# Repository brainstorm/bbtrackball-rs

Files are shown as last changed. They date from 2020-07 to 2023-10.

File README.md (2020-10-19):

# :mouse: Blackberry rusty mouse

The purpose of this project is to build a [blackberry-trackball mouse][bb_trackball] and glue it to the middle of [an (allegedly) ergonomic keyboard][microsoft_natural_keyboard_4000]... **in Rust Embedded**, for the [STM32F042][stm32f042] :)

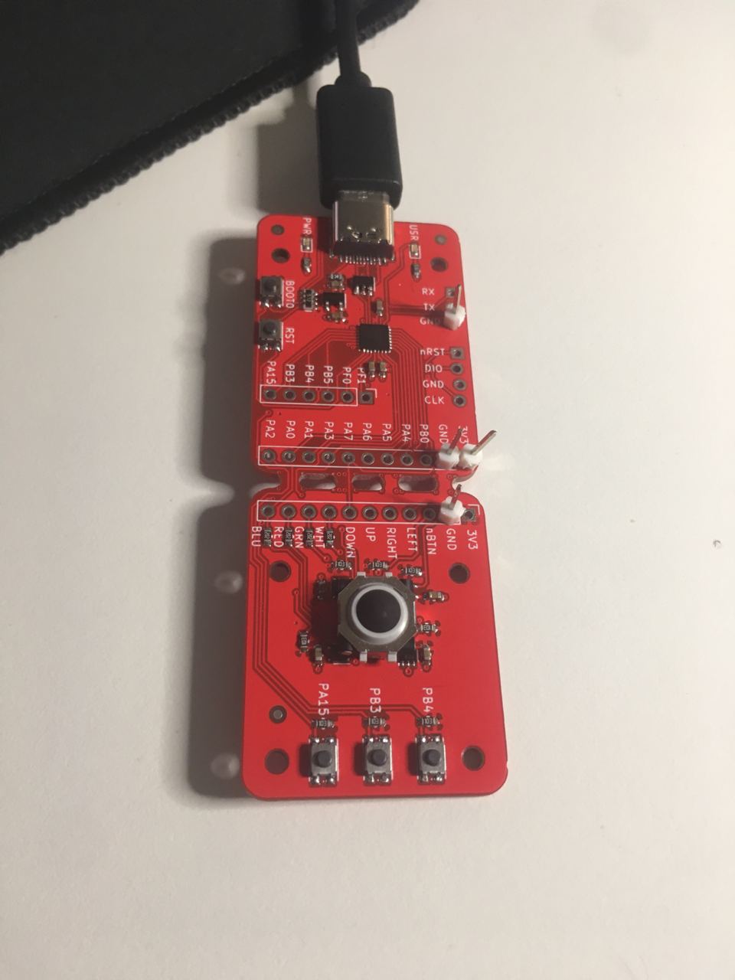
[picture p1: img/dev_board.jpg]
dev_board


This came about [from twitter idea to board, then to Rust Embedded](https://twitter.com/braincode/status/1275406584714104833). The code is based on [RTIC][rtic] rust-embedded framework (formerly known as RTFM). It exclusively uses interrupts *and* [also works on OSX, not only Linux][osx_not_working] (wink wink, nudge nudge, [James][jamesmunns] ;P).

## :rocket: Future improvements shall you take this code with you

* DPI tweaking to have a better trackball accuracy or speed/stepping.
* [Button debouncer][debouncer].
* Remove one of the buttons of the <acronym title="Printed Circuit Board">PCB</acronym>, since it conflicts with one of the trackball GPIOs... oops, hardware blopper ;)
* Add acceleration [like @LSChyi did][add_accel]?
* Perhaps a clever (optical) system to make this experiment actually practical and useful :P
* On OSX the mouse works fine. **On GNU/Linux systems, the mouse might stop responding after ~30 seconds of use**. [This could be related to the Linux USB autosuspend subsystem.](https://askubuntu.com/questions/185274/how-can-i-disable-usb-autosuspend-for-a-specific-device). Try to fix that from the firmware so that it works everywhere?
* If enough people show interest and [**choose to sponsor me**][gh_sponsor_1], I would love to look at how to:
	1. Understand the flash process of the [Beken 3231][beken3231].
	2. Implement an LLVM backend for the [ARM968E-S][ARM968E-S] and have `rustc` working with it.
	3. Goal: **have a sub-$1 bluetooth IC that potentially does all we need and more** plus learn to [implement an LLVM backend from scratch][llvm_cpu0]. Also provide [**a way to upcycle bluetooth hardware, keeping it away from the dumpster.**][old_beken_hardware]
* ~~[Write a simplified RTIC example to return the favour to that amazing rust-embedded community][rtic_hid_example]~~: [Done][rtic_pr].

## :clap: Special thanks to

[@joshajohnson][joshajohnson]
[@mvirkkunen][lumpio]
[@therealprof][therealprof]
[@jamesmunns][jamesmunns]
[@TeXitoi][texitoi]
[@TheZoq2][thezoq2]

And all the folks from the [RTIC matrix.org community][rtic_matrix] for patiently guiding and helping me in this experiment.

[bb_trackball]: https://os.mbed.com/users/AdamGreen/notebook/blackberrytrackballmouse/
[joshajohnson]: https://github.com/joshajohnson
[lumpio]: https://github.com/mvirkkunen/
[therealprof]: https://github.com/therealprof/
[rtic]: https://rtic.rs/
[jamesmunns]: https://github.com/jamesmunns
[osx_not_working]: https://github.com/jamesmunns/OtterPill-rs/commit/8e68fbd5bb1161d8131a99d98c90c3e949f49ec1
[rtic_hid_example]: https://github.com/rtic-rs/rtic-examples/issues/10#issuecomment-677464683
[add_accel]: https://github.com/LSChyi/blackberry-mini-trackball
[debouncer]: https://crates.io/crates/unflappable
[microsoft_natural_keyboard_4000]: https://www.microsoft.com/accessories/en-us/products/keyboards/natural-ergonomic-keyboard-4000/b2m-00012
[stm32f042]: https://www.st.com/en/microcontrollers-microprocessors/stm32f0-series.html
[rtic_pr]: https://github.com/rtic-rs/rtic-examples/pull/12
[gh_sponsor_1]: https://github.com/login?return_to=%2Fsponsors%2Fbrainstorm%2Fsponsorships%3Ftier_id%3D27561
[mitxela]: https://mitxela.com/forum/topic/beken-bk3231
[ARM968E-S]: https://static.docs.arm.com/ddi0311/d/DDI0311.pdf
[beken3231]: https://pdfhost.io/v/3r1I3HggE_BK3231_Bluetooth_HID_SoCpdf.pdf
[llvm_cpu0]: http://jonathan2251.github.io/lbd/TutorialLLVMBackendCpu0.pdf
[texitoi]: https://github.com/TeXitoi
[thezoq2]: https://gitlab.com/TheZoq2/hotas
[old_beken_hardware]: https://mitxela.com/forum/topic/mocute-051-bluetooth-gamepad-bk3231-change-hid-profile-from-keyboard-gamepad
[rtic_matrix]: https://matrix.to/#/#rtic:matrix.org

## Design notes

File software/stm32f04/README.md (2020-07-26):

# Rust STM32 blackberry trackball firmware

Getting onboard with Rust for embedded devices is like 1,2,3 (more details on the [Rust embedded book](https://rust-embedded.github.io/book/)):

```shell
$ curl --proto '=https' --tlsv1.2 -sSf https://sh.rustup.rs | sh
$ rustup target add thumbv6m-none-eabi
$ cargo install cargo-embed
```

Flashing with a standard STLink v2 is easy with `cargo-embed`:

```shell
$ cargo embed --release
    Finished release [optimized] target(s) in 0.04s
    Flashing /Users/romanvg/dev/cchs/keyboard_trackball/software/stm32f04/target/thumbv6m-none-eabi/release/stm32f042
     Erasing sectors ✔ [00:00:00] [#################################################################]  23.00KB/ 23.00KB @  28.29KB/s (eta 0s )
 Programming pages   ✔ [00:00:02] [#################################################################]  23.00KB/ 23.00KB @   7.24KB/s (eta 0s )
    Finished in 2.942s
```

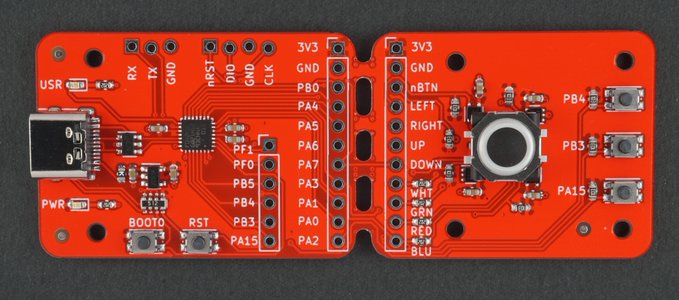
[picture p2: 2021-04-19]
img/josh_studio_photo.jpg

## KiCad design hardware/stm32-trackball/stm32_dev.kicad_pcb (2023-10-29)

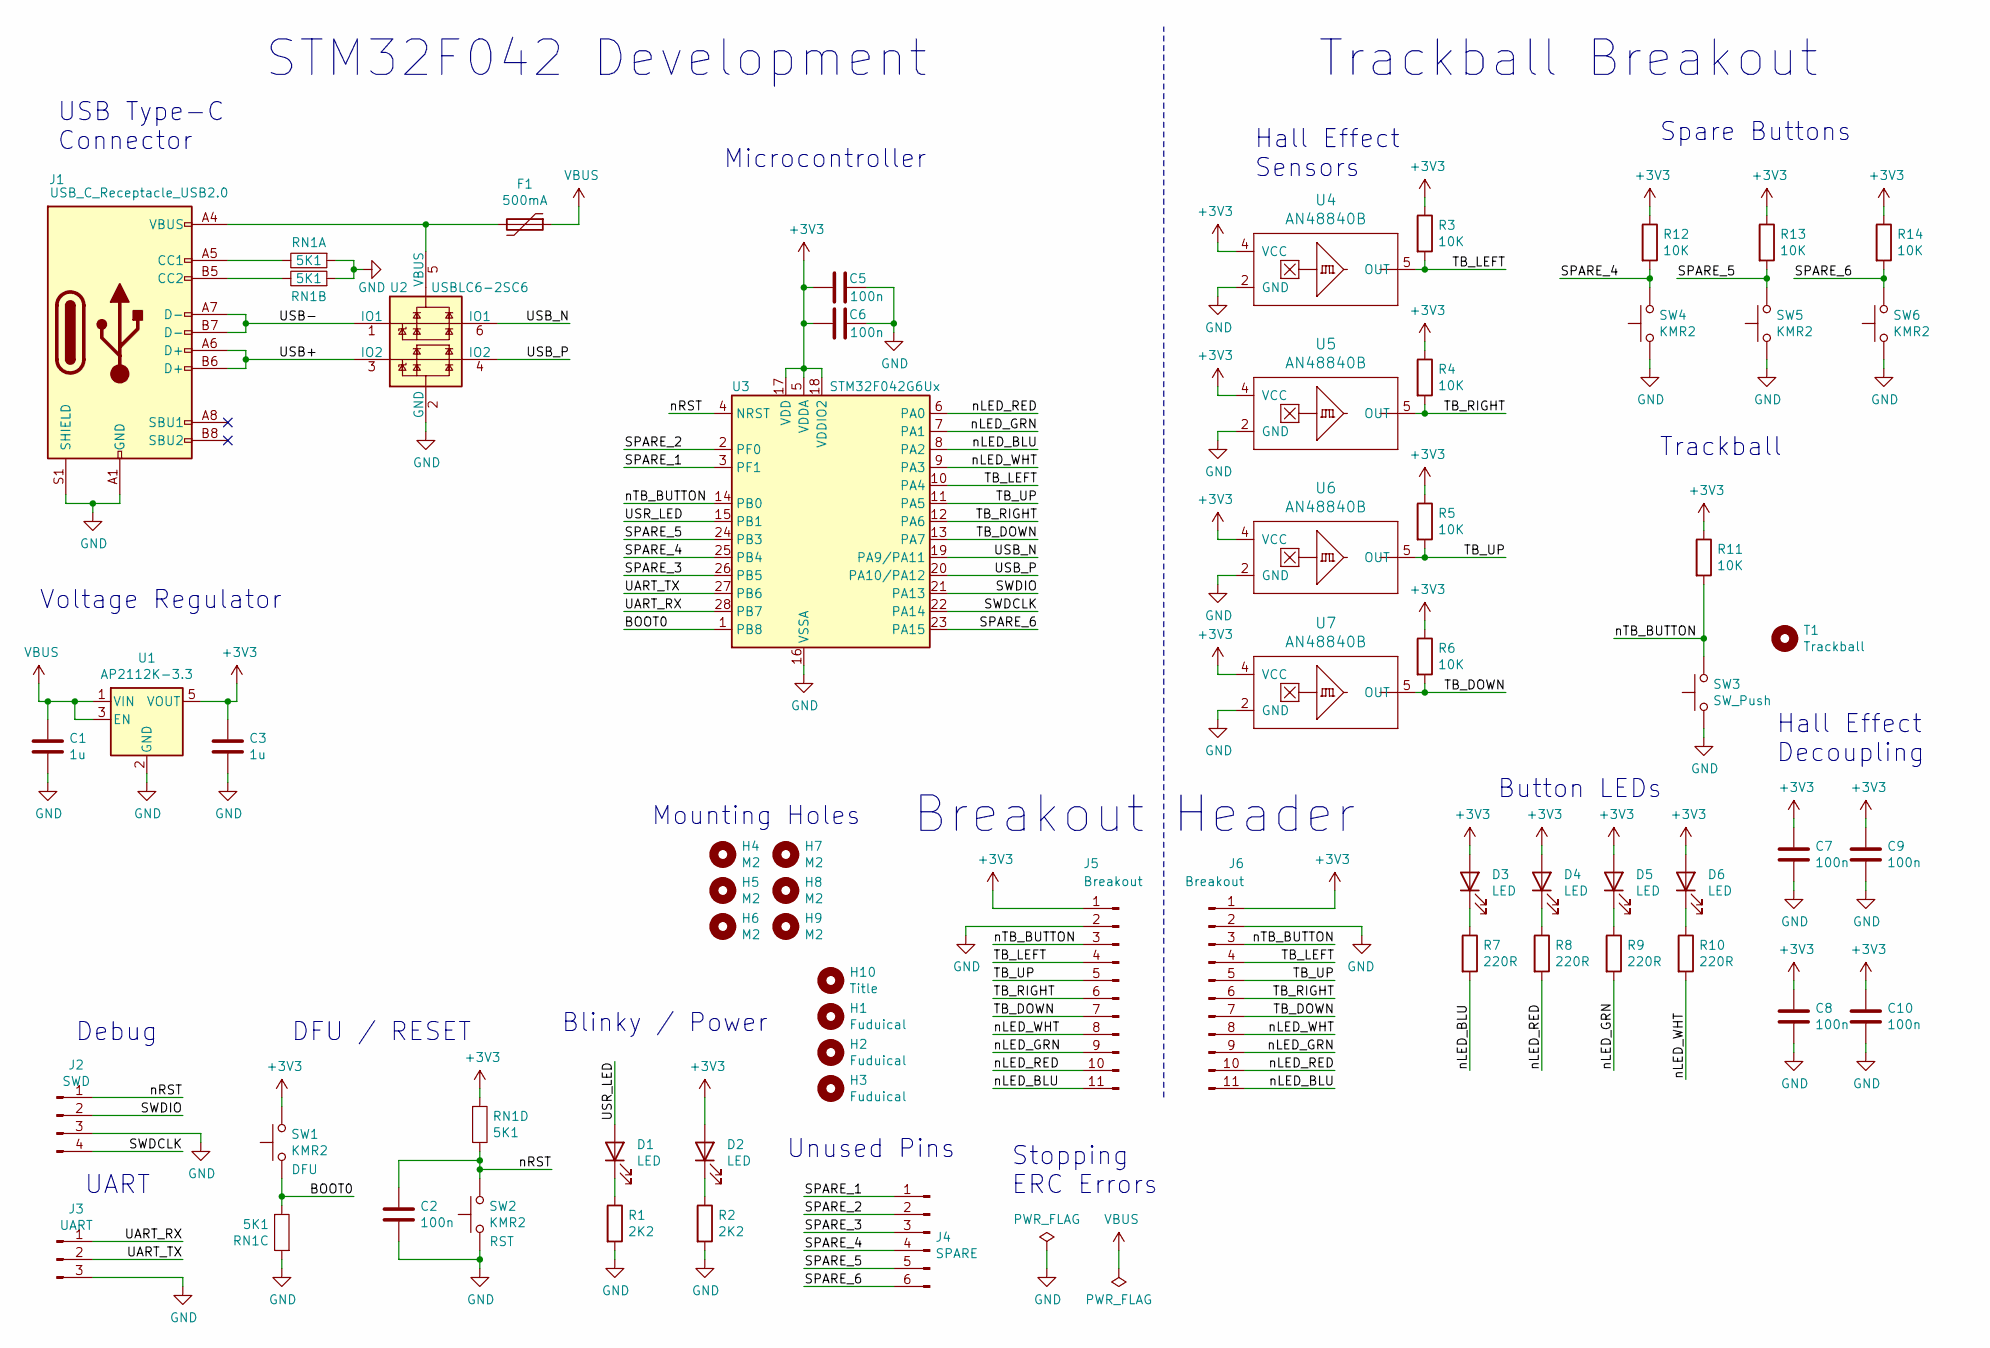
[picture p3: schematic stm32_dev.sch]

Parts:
C1, C3: 1u; C_0603_1608Metric; MPN CL10A105MP8NNNC; LCSC C15849
C2: 100n; C_0603_1608Metric; MPN CL10B104KB8NNNC; LCSC C14663
C5, C6, C7, C8, C9, C10: 100n; C_0603_1608Metric
D1, D2, D3, D4, D5, D6: LED; LED_0603_1608Metric
F1: 500mA; Fuse_0603_1608Metric
H1, H2, H3: Fuduical; Fiducial_1mm_Mask2mm
H4, H5, H6, H7, H8, H9: M2; MountingHole_2.2mm_M2
H10: Title; board-title
J1: USB_C_Receptacle_USB2.0; USB_C_U262-161N-4BVC11; MPN U262-161N-4BVC11; LCSC C319148
J2: SWD; STM_4_PIN_THT_Staggered
J3: UART; STM_3_PIN_THT_Staggered
J4: SPARE; PinHeader_1x06_P2.54mm_Vertical
J5, J6: Breakout; PinHeader_1x11_P2.54mm_Vertical
R1, R2: 2K2; R_0603_1608Metric
R3, R4, R5, R6, R11, R12, R13, R14: 10K; R_0603_1608Metric
R7, R8, R9, R10: 220R; R_0603_1608Metric
RN1: 5K1; R_Array_Convex_4x0603; MPN CAY16-512J4LF; LCSC C12028
SW1, SW2, SW4, SW5, SW6: KMR2; SW_Push_KMR2; MPN PTS840GMSMTRLFS; LCSC C221909
SW3: SW_Push; Trackball_Tactile_Switch
T1: Trackball; TRACKBALL
U1: AP2112K-3.3; SOT-23-5; MPN AP2112K-3.3TRG1; LCSC C51118
U2: USBLC6-2SC6; SOT-23-6
U3: STM32F042G6Ux; QFN-28_4x4mm_P0.5mm
U4, U5, U6, U7: AN48840B; SOT-353_SC-70-5

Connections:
+3V3: C3.2, C5.2, C6.2, C7.1, C8.1, C9.1, C10.1, D2.2 (A), D3.2 (A), D4.2 (A), D5.2 (A), D6.2 (A), J5.1, J6.1, R3.1, R4.1, R5.1, R6.1, R11.1, R12.1, R13.1, R14.1, RN1.1, SW1.2, U1.5 (VOUT), U3.5 (VDDA), U3.17 (VDD), U3.18 (VDDIO2), U4.4 (VCC), U5.4 (VCC), U6.4 (VCC), U7.4 (VCC)
/BOOT0: RN1.7, SW1.1, U3.1 (PB8)
/SPARE_1: J4.1, U3.3 (PF1)
/SPARE_2: J4.2, U3.2 (PF0)
/SPARE_3: J4.3, U3.26 (PB5)
/SPARE_4: J4.4, R12.2, SW4.2, U3.25 (PB4)
/SPARE_5: J4.5, R13.2, SW5.2, U3.24 (PB3)
/SPARE_6: J4.6, R14.2, SW6.2, U3.23 (PA15)
/SWDCLK: J2.4, U3.22 (PA14)
/SWDIO: J2.2, U3.21 (PA13)
/TB_DOWN: J5.7, J6.7, R6.2, U3.13 (PA7), U7.5 (OUT)
/TB_LEFT: J5.4, J6.4, R3.2, U3.10 (PA4), U4.5 (OUT)
/TB_RIGHT: J5.6, J6.6, R4.2, U3.12 (PA6), U5.5 (OUT)
/TB_UP: J5.5, J6.5, R5.2, U3.11 (PA5), U6.5 (OUT)
/UART_RX: J3.1, U3.28 (PB7)
/UART_TX: J3.2, U3.27 (PB6)
/USB+: J1.A6 (D+), J1.B6 (D+), U2.3 (IO2)
/USB-: J1.A7 (D-), J1.B7 (D-), U2.1 (IO1)
/USB_N: U2.6 (IO1), U3.19 (PA9/PA11)
/USB_P: U2.4 (IO2), U3.20 (PA10/PA12)
/USR_LED: D1.2 (A), U3.15 (PB1)
/nLED_BLU: J5.11, J6.11, R7.2, U3.8 (PA2)
/nLED_GRN: J5.9, J6.9, R9.2, U3.7 (PA1)
/nLED_RED: J5.10, J6.10, R8.2, U3.6 (PA0)
/nLED_WHT: J5.8, J6.8, R10.2, U3.9 (PA3)
/nRST: C2.1, J2.1, RN1.8, SW2.2, U3.4 (NRST)
/nTB_BUTTON: J5.3, J6.3, R11.2, SW3.2, U3.14 (PB0)
GND: C1.1, C2.2, C3.1, C5.1, C6.1, C7.2, C8.2, C9.2, C10.2, J1.A1 (GND), J1.A12 (GND), J1.B1 (GND), J1.B12 (GND), J1.S1 (SHIELD), J2.3, J3.3, J5.2, J6.2, R1.2, R2.2, RN1.2, RN1.3, RN1.4, SW2.1, SW3.1, SW4.1, SW5.1, SW6.1, U1.2 (GND), U2.2 (GND), U3.16 (VSSA), U4.2 (GND), U5.2 (GND), U6.2 (GND), U7.2 (GND)
unnamed: D1.1 (K), R1.1
unnamed: D2.1 (K), R2.1
unnamed: D3.1 (K), R7.1
unnamed: D4.1 (K), R8.1
unnamed: D5.1 (K), R9.1
unnamed: D6.1 (K), R10.1
unnamed: F1.2, J1.A4 (VBUS), J1.A9 (VBUS), J1.B4 (VBUS), J1.B9 (VBUS), U2.5 (VBUS)
unnamed: J1.A5 (CC1), RN1.5
unnamed: J1.B5 (CC2), RN1.6
VBUS: C1.2, F1.1, U1.1 (VIN), U1.3 (EN)

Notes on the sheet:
USB Type-C Connector
Voltage Regulator
DFU / RESET
Microcontroller
Debug
UART
Blinky / Power
STM32F042 Development
Trackball Breakout
Hall Effect Decoupling
Button LEDs
Breakout Header
Unused Pins
Hall Effect Sensors
Trackball
Mounting Holes
Stopping ERC Errors
Spare Buttons

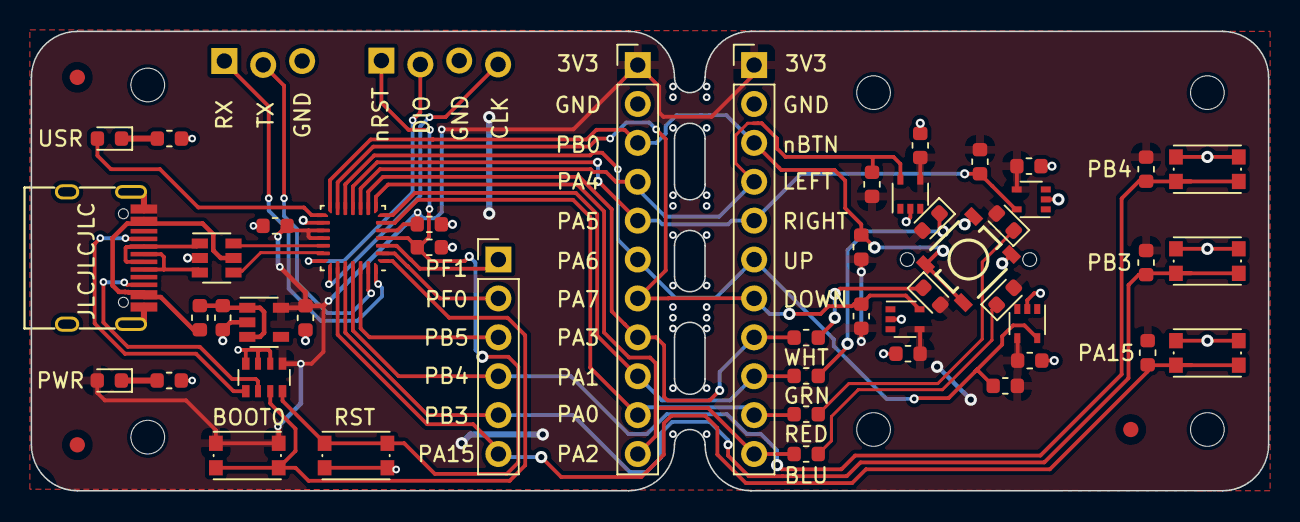
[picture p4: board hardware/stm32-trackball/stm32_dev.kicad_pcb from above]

Board: 2 copper layers, 80.8 x 30.0 mm, 61 parts (1 on the bottom side), 38 nets.

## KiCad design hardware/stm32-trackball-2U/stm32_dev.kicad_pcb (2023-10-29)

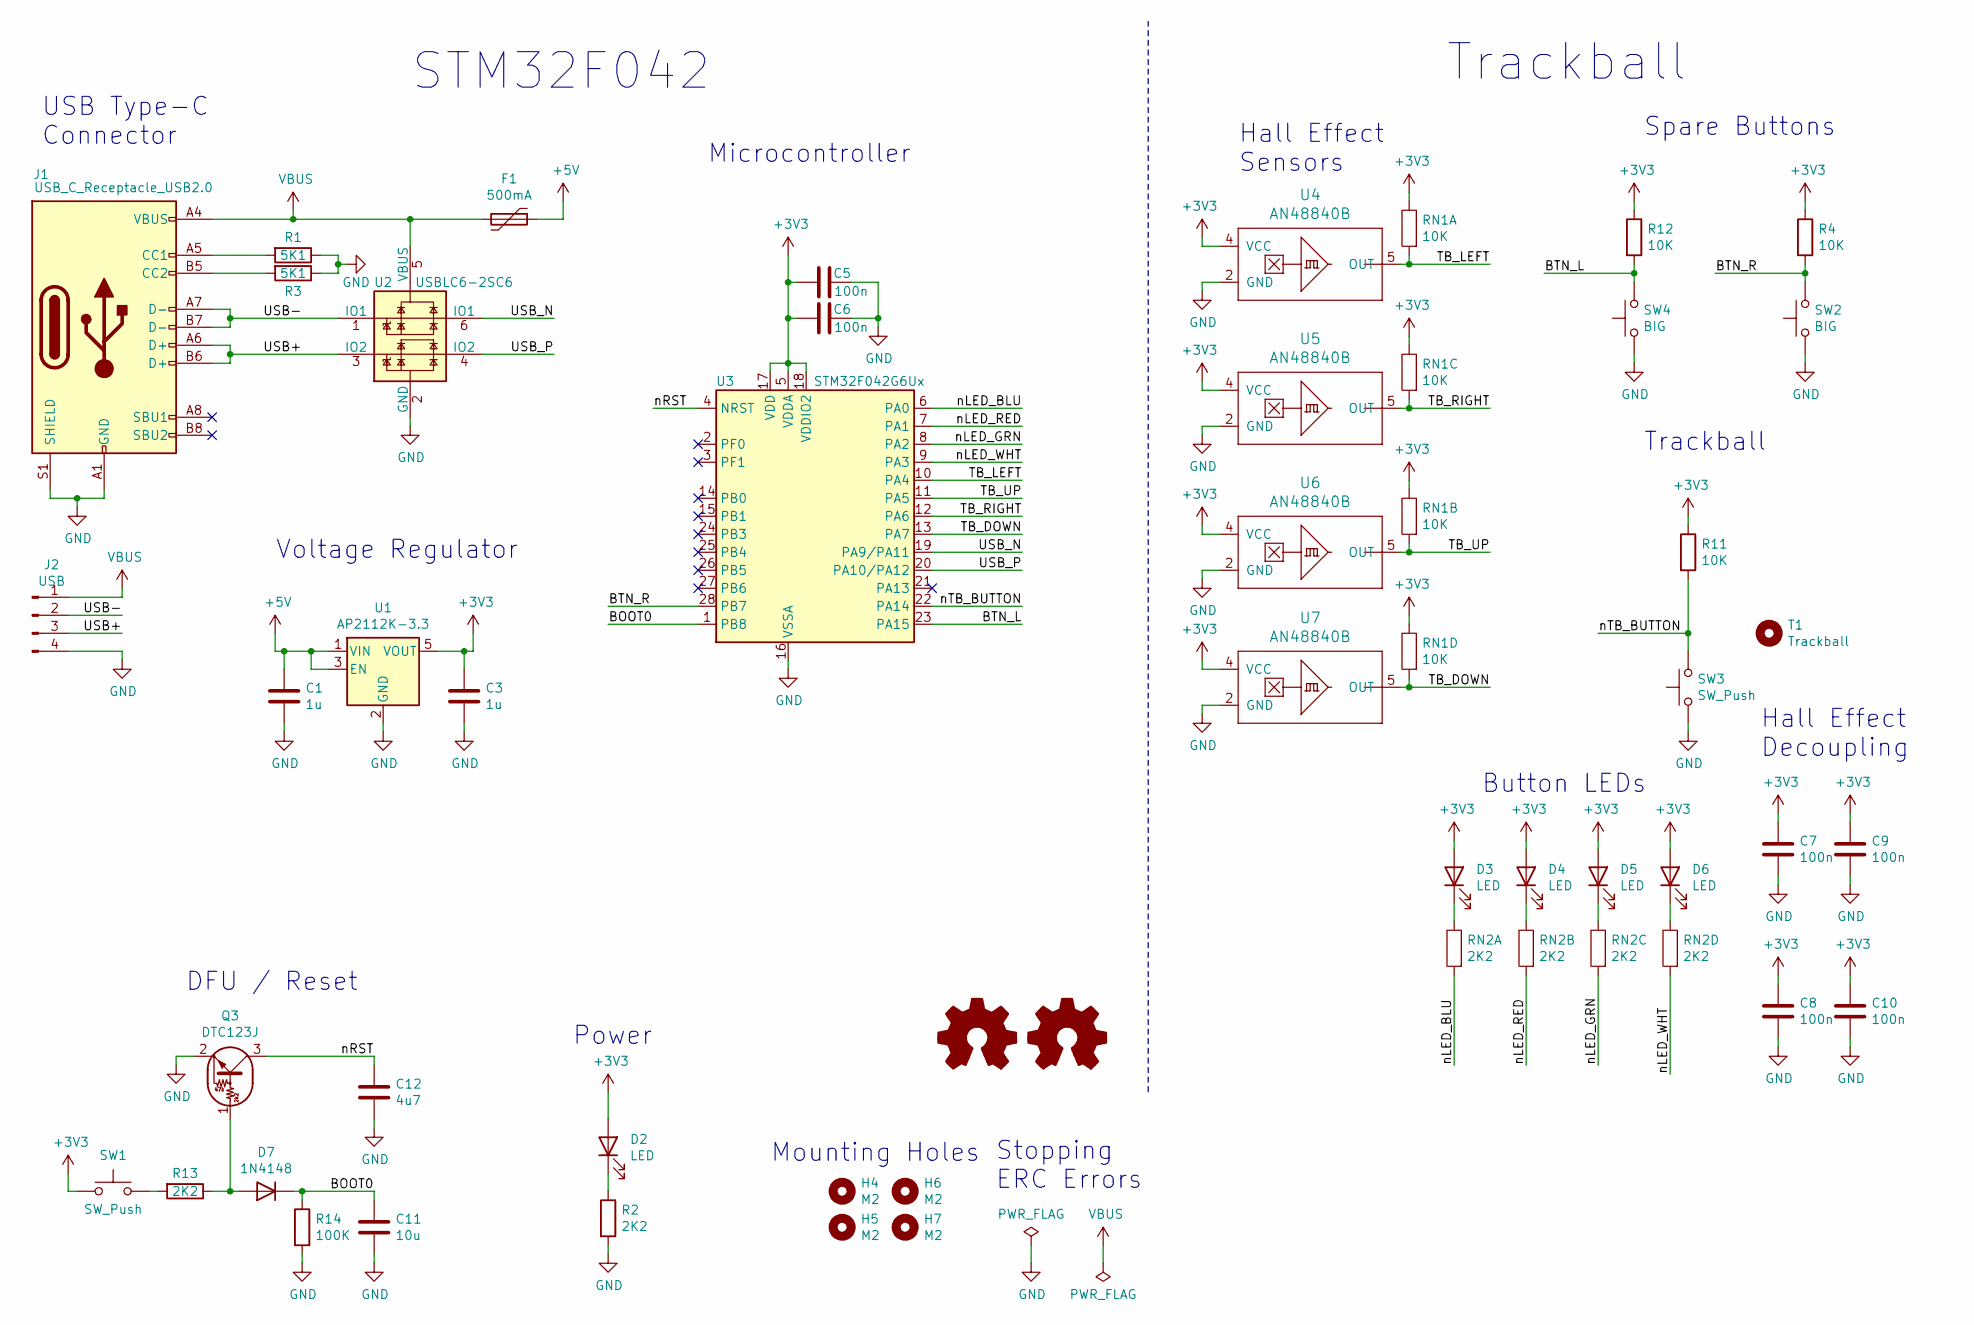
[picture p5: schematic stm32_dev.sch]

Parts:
C1, C3: 1u; C_0402_1005Metric; MPN CL10A105MP8NNNC; LCSC C15849
C5, C6, C7, C8, C9, C10: 100n; C_0402_1005Metric
C11: 10u; C_0402_1005Metric; MPN CL10A106KP8NNNC; JLCSMT C19702
C12: 4u7; C_0402_1005Metric; MPN CL10A475KO8NNNC; JLCSMT C19666
D2, D3, D4, D5, D6: LED; LED_0603_1608Metric
D7: 1N4148; D_SOD-323; MPN 1N4148W; JLCSMT C81598
F1: 500mA; Fuse_0603_1608Metric
H4, H5, H6, H7: M2; MountingHole_2.2mm_M2
J1: USB_C_Receptacle_USB2.0; USB_C_U262-161N-4BVC11; MPN U262-161N-4BVC11; LCSC C319148
J2: USB; PinHeader_1x04_P1.27mm_Vertical
LOGO1: OSHW Mask; OSHW_Logo_3.6x3.6_F.Mask
LOGO2: Board Details; board-title
Q3: DTC123J; SOT-23
R1, R3: 5K1; R_0402_1005Metric; MPN 0603WAF1501T5E; JLCSMT C22843
R2: 2K2; R_0402_1005Metric
R4, R11, R12: 10K; R_0402_1005Metric
R13: 2K2; R_0402_1005Metric; MPN 0603WAF1501T5E; JLCSMT C22843
R14: 100K; R_0402_1005Metric; MPN 0603WAF1003T5E; JLCSMT C25803
RN1: 10K; R_Array_Convex_4x0402
RN2: 2K2; R_Array_Convex_4x0402
SW1: SW_Push; Panasonic_EVQPUL_EVQPUC
SW2, SW4: BIG; Switch_SMT_SKPMAPE010
SW3: SW_Push; Trackball_Tactile_Switch
T1: Trackball; TRACKBALL
U1: AP2112K-3.3; SOT-23-5; MPN AP2112K-3.3TRG1; LCSC C51118
U2: USBLC6-2SC6; SOT-666
U3: STM32F042G6Ux; QFN-28_4x4mm_P0.5mm
U4, U5, U6, U7: AN48840B; SOT-353_SC-70-5

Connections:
+3V3: C3.2, C5.2, C6.2, C7.1, C8.1, C9.1, C10.1, D2.2 (A), D3.2 (A), D4.2 (A), D5.2 (A), D6.2 (A), R4.1, R11.1, R12.1, RN1.5, RN1.6, RN1.7, RN1.8, SW1.1, U1.5 (VOUT), U3.5 (VDDA), U3.17 (VDD), U3.18 (VDDIO2), U4.4 (VCC), U5.4 (VCC), U6.4 (VCC), U7.4 (VCC)
+5V: C1.2, F1.1, U1.1 (VIN), U1.3 (EN)
/BOOT0: C11.1, D7.1 (K), R14.1, U3.1 (PB8)
/BTN_L: R12.2, SW4.2, U3.23 (PA15)
/BTN_R: R4.2, SW2.2, U3.28 (PB7)
/TB_DOWN: RN1.1, U3.13 (PA7), U7.5 (OUT)
/TB_LEFT: RN1.4, U3.10 (PA4), U4.5 (OUT)
/TB_RIGHT: RN1.2, U3.12 (PA6), U5.5 (OUT)
/TB_UP: RN1.3, U3.11 (PA5), U6.5 (OUT)
/USB+: J1.A6 (D+), J1.B6 (D+), J2.3, U2.3 (IO2)
/USB-: J1.A7 (D-), J1.B7 (D-), J2.2, U2.1 (IO1)
/USB_N: U2.6 (IO1), U3.19 (PA9/PA11)
/USB_P: U2.4 (IO2), U3.20 (PA10/PA12)
/nLED_BLU: RN2.4, U3.6 (PA0)
/nLED_GRN: RN2.2, U3.8 (PA2)
/nLED_RED: RN2.3, U3.7 (PA1)
/nLED_WHT: RN2.1, U3.9 (PA3)
/nRST: C12.1, Q3.3 (C), U3.4 (NRST)
/nTB_BUTTON: R11.2, SW3.2, U3.22 (PA14)
GND: C1.1, C3.1, C5.1, C6.1, C7.2, C8.2, C9.2, C10.2, C11.2, C12.2, J1.A1 (GND), J1.A12 (GND), J1.B1 (GND), J1.B12 (GND), J1.S1 (SHIELD), J2.4, Q3.2 (E), R1.1, R2.2, R3.1, R14.2, SW2.1, SW3.1, SW4.1, U1.2 (GND), U2.2 (GND), U3.16 (VSSA), U4.2 (GND), U5.2 (GND), U6.2 (GND), U7.2 (GND)
unnamed: D2.1 (K), R2.1
unnamed: D3.1 (K), RN2.5
unnamed: D4.1 (K), RN2.6
unnamed: D5.1 (K), RN2.7
unnamed: D6.1 (K), RN2.8
unnamed: D7.2 (A), Q3.1 (B), R13.1
unnamed: J1.A5 (CC1), R1.2
unnamed: J1.B5 (CC2), R3.2
unnamed: R13.2, SW1.2
VBUS: F1.2, J1.A4 (VBUS), J1.A9 (VBUS), J1.B4 (VBUS), J1.B9 (VBUS), J2.1, U2.5 (VBUS)

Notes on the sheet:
USB Type-C Connector
Microcontroller
Power
STM32F042
Trackball
Hall Effect Decoupling
Button LEDs
Hall Effect Sensors
Mounting Holes
Stopping ERC Errors
Spare Buttons
DFU / Reset
Voltage Regulator

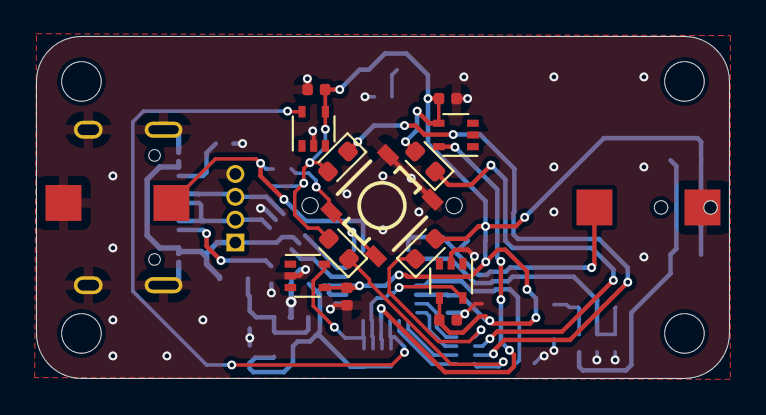
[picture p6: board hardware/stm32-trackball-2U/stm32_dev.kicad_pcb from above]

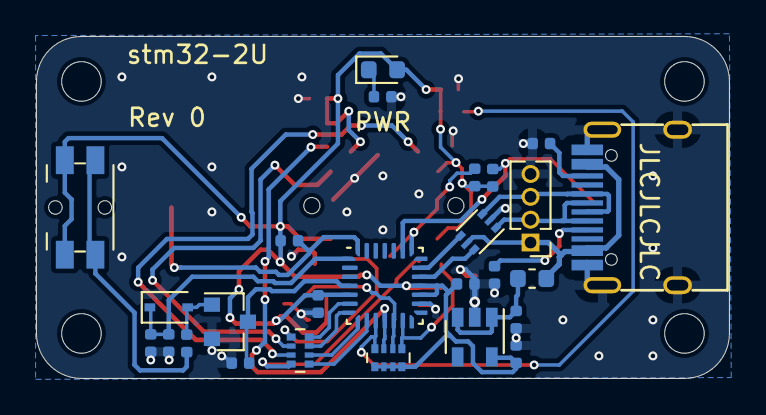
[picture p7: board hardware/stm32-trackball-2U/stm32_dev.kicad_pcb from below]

Board: 2 copper layers, 38.5 x 19.0 mm, 48 parts (28 on the bottom side), 30 nets.

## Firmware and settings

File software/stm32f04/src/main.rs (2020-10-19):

#![deny(unsafe_code)]
#![deny(warnings)]
#![no_std]
#![no_main]

use panic_halt as _;
use rtic::app;
use rtic::{Exclusive, Mutex};
use rtt_target::{rprintln, rtt_init_print};

use stm32f0xx_hal::{
    gpio::gpioa::{PA0, PA1, PA15, PA2, PA3, PA4, PA5, PA6, PA7},
    gpio::gpiob::{PB1, PB3, PB4},
    gpio::{Input, Output, PullUp, PushPull},
    pac,
    prelude::*,
    usb,
};

use usb_device::{bus::UsbBusAllocator, prelude::*};

use usbd_hid::descriptor::generator_prelude::*;
use usbd_hid::descriptor::MouseReport;
use usbd_hid::hid_class::HIDClass;

use cortex_m::asm::delay as delay;
use cortex_m::interrupt::free as disable_interrupts;

#[app(device = stm32f0xx_hal::pac, peripherals = true)]
const APP: () = {
    struct Resources {
        usb_bus: &'static UsbBusAllocator<usb::UsbBusType>,
        usb_device: UsbDevice<'static, usb::UsbBusType>,
        usb_hid: HIDClass<'static, usb::UsbBusType>,
        exti: pac::EXTI,
        usr_led: PB1<Output<PushPull>>,
        button_right: PA15<Input<PullUp>>,
        button_left: PB4<Input<PullUp>>,
        button5: PB3<Input<PullUp>>,
        tb_left: PA4<Input<PullUp>>,
        tb_up: PA5<Input<PullUp>>,
        tb_right: PA6<Input<PullUp>>,
        tb_down: PA7<Input<PullUp>>,
        bbled_red: PA0<Output<PushPull>>,
        bbled_grn: PA1<Output<PushPull>>,
        bbled_blu: PA2<Output<PushPull>>,
        bbled_wht: PA3<Output<PushPull>>,
    }

    #[init]
    fn init(ctx: init::Context) -> init::LateResources {
        static mut USB_BUS: Option<UsbBusAllocator<usb::UsbBusType>> = None;

        // RTT handler
        rtt_init_print!();

        // Alias peripherals
        let mut dp: pac::Peripherals = ctx.device;

        // This code enables clock for SYSCFG and remaps USB pins to PA9 and PA10.
        usb::remap_pins(&mut dp.RCC, &mut dp.SYSCFG);

        // TODO: Power on bbled dance (light up LEDs in a fun pattern when powered on)

        rprintln!("Initializing peripherals");
        let mut rcc = dp
            .RCC
            .configure()
            .usbsrc(stm32f0xx_hal::rcc::USBClockSource::HSI48)
            .hsi48()
            .enable_crs(dp.CRS)
            .sysclk(48.mhz())
            .pclk(24.mhz())
            .freeze(&mut dp.FLASH);

        // Set up GPIO registers for USR LED and Buttons
        let gpiob = dp.GPIOB.split(&mut rcc);
        let (usr_led, button_left, button5) = disable_interrupts(|cs| {
            (
                gpiob.pb1.into_push_pull_output(cs),
                gpiob.pb4.into_pull_up_input(cs),
                gpiob.pb3.into_pull_up_input(cs),
            )
        });

        // LEDs and USB
        let gpioa = dp.GPIOA.split(&mut rcc);
        let (
            bbled_red,
            bbled_grn,
            bbled_blu,
            bbled_wht,
            tb_left,
            tb_up,
            tb_right,
            tb_down,
            button_right,
            usb_dm,
            usb_dp,
        ) = disable_interrupts(|cs| {
            (
                gpioa.pa0.into_push_pull_output(cs),
                gpioa.pa1.into_push_pull_output(cs),
                gpioa.pa2.into_push_pull_output(cs),
                gpioa.pa3.into_push_pull_output(cs),
                gpioa.pa4.into_pull_up_input(cs),
                gpioa.pa5.into_pull_up_input(cs),
                gpioa.pa6.into_pull_up_input(cs),
                gpioa.pa7.into_pull_up_input(cs),
                gpioa.pa15.into_pull_up_input(cs),
                gpioa.pa11,
                gpioa.pa12,
            )
        });

        // Enable external interrupt for 3 aux buttons...
        dp.SYSCFG.exticr1.write(|w| w.exti3().pb3());
        // dp.SYSCFG.exticr2.write(|w| { w.exti4().pb4() }); // Disable spare button in favor of tb_left
        dp.SYSCFG.exticr4.write(|w| w.exti15().pa15());
        //... and for pulses on trackball
        dp.SYSCFG.exticr2.write(|w| w.exti4().pa4());
        dp.SYSCFG.exticr2.write(|w| w.exti5().pa5());
        dp.SYSCFG.exticr2.write(|w| w.exti6().pa6());
        dp.SYSCFG.exticr2.write(|w| w.exti7().pa7());

        // Set interrupt mask for all the above
        dp.EXTI.imr.write(|w| {
            w.mr3().set_bit();
            w.mr4().set_bit();
            w.mr5().set_bit();
            w.mr6().set_bit();
            w.mr7().set_bit();
            w.mr15().set_bit()
        });

        // Set interrupt rising trigger
        dp.EXTI.rtsr.write(|w| {
            w.tr3().set_bit();
            w.tr4().set_bit();
            w.tr5().set_bit();
            w.tr6().set_bit();
            w.tr7().set_bit();
            w.tr15().set_bit()
        });

        let usb = usb::Peripheral {
            usb: dp.USB,
            pin_dm: usb_dm,
            pin_dp: usb_dp,
        };

        *USB_BUS = Some(usb::UsbBus::new(usb));

        rprintln!("Preparing HID mouse...");
        let usb_hid = HIDClass::new(USB_BUS.as_ref().unwrap(), MouseReport::desc(), 60);

        rprintln!("Defining USB parameters...");
        let usb_device = UsbDeviceBuilder::new(USB_BUS.as_ref().unwrap(), UsbVidPid(0, 0x3821))
            .manufacturer("JoshFTW")
            .product("BBTrackball")
            .serial_number("RustFW")
            .device_class(0x00)
            .device_sub_class(0x00)
            .device_protocol(0x00)
            .build();

        rprintln!("Instantiating dp.EXTI...");
        let exti = dp.EXTI;
        rprintln!("Defining late resources...");

        init::LateResources {
            usb_bus: USB_BUS.as_ref().unwrap(),
            usb_device,
            usb_hid,
            exti,
            usr_led,
            button_right,
            button_left,
            button5,
            tb_left,
            tb_up,
            tb_right,
            tb_down,
            bbled_red,
            bbled_grn,
            bbled_blu,
            bbled_wht,
        }
    }

    #[idle(resources = [usb_device, usb_hid])]
    fn idle(_: idle::Context) -> ! {
        loop {
            // Wake From Interrupt
            cortex_m::asm::wfi();
        }
    }

    #[task(binds = EXTI2_3, resources = [exti, usb_hid])]
    fn exti2_3_interrupt(ctx: exti2_3_interrupt::Context) {
        rprintln!("Interrupts happening on EXTI2_3");

        let hid = ctx.resources.usb_hid;

        match ctx.resources.exti.pr.read().bits() {
            0x8 => {
                rprintln!("Right Button");
                send_mouse_report(Exclusive(hid), 0, 0, 3);
                delay(1000);
                send_mouse_report(Exclusive(hid), 0, 0, 0);
                ctx.resources.exti.pr.write(|w| w.pif3().set_bit()); // Clear interrupt
            }

            _ => rprintln!("Some other bits were pushed around on EXTI2_3 ;)"),
        }
    }

    #[task(binds = EXTI4_15, resources = [exti, usb_device, usb_hid, usr_led, bbled_red, bbled_grn, bbled_wht, bbled_blu])]
    fn exti_4_15_interrupt(ctx: exti_4_15_interrupt::Context) {
        rprintln!("Interrupts happening on EXTI for PA15...");

        let hid = ctx.resources.usb_hid;
        let usr_led = ctx.resources.usr_led;

        match ctx.resources.exti.pr.read().bits() {
            0x8000 => {
                rprintln!("Left Button");
                ctx.resources.exti.pr.write(|w| w.pif15().set_bit()); // Clear interrupt
                send_mouse_report(Exclusive(hid), 0, 0, 1);
                delay(1000);
                send_mouse_report(Exclusive(hid), 0, 0, 0);
                usr_led.toggle().ok();
            }
            0x10 => {
                rprintln!("tb_left triggered!");
                ctx.resources.exti.pr.write(|w| w.pif4().set_bit());
                send_mouse_report(Exclusive(hid), 5, 0, 0);
                usr_led.toggle().ok();
            }
            0x20 => {
                rprintln!("tb_up triggered!");
                ctx.resources.exti.pr.write(|w| w.pif5().set_bit());
                send_mouse_report(Exclusive(hid), 0, 5, 0);
                usr_led.toggle().ok();
            }
            0x40 => {
                rprintln!("tb_right triggered!");
                ctx.resources.exti.pr.write(|w| w.pif6().set_bit());
                send_mouse_report(Exclusive(hid), -5, 0, 0);
                usr_led.toggle().ok();
            }
            0x80 => {
                rprintln!("tb_down triggered!");
                ctx.resources.exti.pr.write(|w| w.pif7().set_bit());
                send_mouse_report(Exclusive(hid), 0, -5, 0);
                usr_led.toggle().ok();
            }

            _ => rprintln!("Some other bits were pushed around on EXTI4_15 ;)"),
        }
    }

    #[task(binds = USB, resources = [usb_device, usb_hid])]
    fn usb_handler(ctx: usb_handler::Context) {
        rprintln!("USB interrupt received.");

        let dev = ctx.resources.usb_device;
        let hid = ctx.resources.usb_hid;

        // USB dev poll only in the interrupt handler
        dev.poll(&mut [hid]);
    }
};

fn send_mouse_report(
    mut shared_hid: impl Mutex<T = HIDClass<'static, usb::UsbBusType>>,
    x: i8,
    y: i8,
    buttons: u8,
) {
    let mr = MouseReport { x, y, buttons };

    shared_hid.lock(|hid| {
        rprintln!("Sending mouse report...");
        hid.push_input(&mr).ok();
    });
}

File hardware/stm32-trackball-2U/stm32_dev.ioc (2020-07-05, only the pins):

Mcu.UserName=STM32F042G6Ux
PA0.GPIO_Label=nLED_RED
PA0.Signal=S_TIM2_CH1_ETR
PA1.GPIO_Label=nLED_GRN
PA1.Signal=S_TIM2_CH2
PA11.Signal=USB_DM
PA12.Signal=USB_DP
PA13.Signal=SYS_SWDIO
PA14.Signal=SYS_SWCLK
PA2.GPIO_Label=nLED_BLU
PA2.Signal=S_TIM2_CH3
PA3.GPIO_Label=nLED_WHT
PA3.Signal=S_TIM2_CH4
PA4.GPIO_Label=TB_LEFT
PA4.Signal=GPIO_Input
PA5.GPIO_Label=TB_RIGHT
PA5.Signal=GPIO_Input
PA6.GPIO_Label=TB_UP
PA6.Signal=GPIO_Input
PA7.GPIO_Label=TB_DOWN
PA7.Signal=GPIO_Input
PB0.GPIO_Label=TB_BUTTON
PB0.Signal=GPIO_Input
PB1.GPIO_Label=USR_LED
PB1.Signal=GPIO_Output
PB6.Signal=USART1_TX
PB7.Signal=USART1_RX

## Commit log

2020-06-25 Add minimal explanation and kicad automation
2020-06-25 add kicad gitignore
2020-06-25 add josh kicad lib
2020-06-25 add sparkfun breakout design files
    [SparkFun_Blackberry_Trackballer_Breakout_v13.brd, SparkFun_Blackberry_Trackballer_Breakout_v13.kicad_pcb, SparkFun_Blackberry_Trackballer_Breakout_v13.sch]
2020-06-25 inital schematic +footprint import
    [stm32_dev.kicad_pcb, stm32_dev.sch]
2020-06-25 add button datasheet
2020-06-26 Restrict sch to kicad-only schematics, otherwise their clash with the Eagle ones
2020-06-26 Bump to kicad-exports 1.0, use full bom instead of just ibom, explicit schematic and boards files
2020-06-26 Indicate full path although we need board layout for correct bom generation, discard .DS_Store trash
2020-06-27 Rough board layout (without routing yet), arrange components, add fiducials, pours, etc...
    [stm32_dev.kicad_pcb]
2020-06-27 Versions shall never appear on filenames nor folders, that's what version control is for :D
    [stm32_dev.kicad_pcb, stm32_dev.sch]
2020-06-27 Use kicad-exports full potential
2020-06-27 Everybody gets schematic and board now...
2020-06-27 partial layout, trackball TODO
    [stm32_dev.kicad_pcb, stm32_dev.sch]
2020-06-28 fix trackball led / hall position
    [stm32_dev.kicad_pcb]
2020-06-28 attempting to fix broken symbol
    [stm32_dev.sch]
2020-06-28 move symbol to updated kicad lib
    [stm32_dev.sch]
2020-06-28 Trackball breakout mounting holes and almost-finished routing
    [stm32_dev.kicad_pcb]
2020-06-30 Flipped TB_UP and TB_RIGHT for more convenient routing on the trackball. Almost finished routing, pad-on-pad issues with the Switch and Trackball footprints prevent routing GNDs
    [stm32_dev.kicad_pcb, stm32_dev.sch]
2020-06-30 Removed S1 in favour of SW3, first pass (naive) routing finished
    [stm32_dev.kicad_pcb]
2020-06-30 Rename duplicate REF** names, they mess up with DSN export and pick and place machines
    [stm32_dev.kicad_pcb]
2020-06-30 add mounting holes to schematic, improve decoupling cap placement
    [stm32_dev.kicad_pcb, stm32_dev.sch]
2020-07-02 added extra buttons
    [stm32_dev.kicad_pcb, stm32_dev.sch]
2020-07-05 off to fab
    [stm32_dev.kicad_pcb, stm32_dev.sch]
2020-07-26 Add preliminary skeleton for STM32F04G6G IC from https://github.com/stm32-rs/stm32-usbd-examples/blob/master/example-stm32f042k6/src/main.rs and https://github.com/agalakhov/usbd-hid-device-example/b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
    [main.rs]
2020-08-02 Define buttons, led, usb peripheral, add USB HID report struct... meanwhile, it blinks ;)
2020-08-04 Correctly define the rest of I/O, next up: interrupts and hall sensors
    [main.rs]
2020-08-09 Add USB interrupt mechanism and idle loop
2020-08-18 USB device was not enumerating, the only thing that was preventing it from working was the PA9/10/11/12 remapping. Also added RTT debugging and more hints and tips from @mvirkkunen and other really h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
    [main.rs]
2020-08-20 Remove most of the bloat, HID can be implemented with leaner crate. Introduce RTT based debugging via probe-rs on the STLinkv2, focusing on external interrupts now.
2020-08-22 Great feedback from RTIC matrix.org channel, still needs some more work handling interrupts, the stm32f0xx_hal is mature but has some quirks compared to other more modern HALs (i.e not having helper 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
2020-08-24 PA15 enters in the interrupt code but fails to clear the interrupt
    [main.rs]
2020-08-24 PA15 button interrupts working as expected, finally
2020-08-26 Interrupt working for PA15 but failing to be cleared for the rest :-?
    [main.rs]
2020-08-29 Use write instead of modify for the interrupt setup and masking. Try to figure out why PA15 triggers fine but PB3 and PB4 get stuck into the interrupt task code (failing to clear the interrupt bit no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
    [main.rs]
2020-08-30 Just know your bits and the right ones you should be really be clearing for the interrupts. Cleanup as well
2020-08-30 All trackball interrupts working, we should disambiguate PB4 and PA4 somehow... perhaps switch to polling for those two? :-S
2020-08-30 Adding falling edge interrupts for conflicted interrupt lines
2020-08-30 Overlapping interrupt definitions result in newest taking priority
2020-09-03 How does one send USB interrupts w/ HID reports after an USB interrupt has been triggered?
2020-09-06 usb_dev polling on the USB interrupt and passing the mouse report to the polling does not seem to cut it :/
2020-09-06 Build, change device class to 0xFE as seen in https://github.com/jamesmunns/OtterPill-rs/blob/master/hello-mouse/src/main.rs
    [main.rs]
2020-09-12 Apparently order matters. If I init usb_hid **before** usb_dev, all interrupts work, the opposite freezes the program right after defining usb_hid :-S
2020-09-12 Clear up pending interrupts on the loop(), cleanup unnecessary cargo.toml feature definitions
2020-09-12 More rprintn statements to follow the program flow more closely. Cheekely change the VID:PID to my (working) Aliexpress USB mouse... doesn't matter though, no effect. Not using wfi triggers some sort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
    [main.rs]
2020-09-14 Leds lighting on mouse report sending, adding usb_dev polling and report sending on the idle loop too as suggested by RTIC Lumpio
2020-09-21 The general idea is to poll() only in the interrupt handler, and after that attempt to read data (in your case you never read so no need to), thanks @mvirkkunen
2020-09-24 Finally works on OSX :D... it was the VID:PID, never define an Apple product when it is not ;)
2020-09-25 Invert left/right, double range, class is not MISC but... autodetected via MouseReports I guess?
    [main.rs]
2020-09-27 Remove Sparkfun trackballer
    [SparkFun_Blackberry_Trackballer_Breakout_v13.brd, SparkFun_Blackberry_Trackballer_Breakout_v13.kicad_pcb, SparkFun_Blackberry_Trackballer_Breakout_v13.sch]
2020-09-27 Mention PB4 (or was it PB3?) interrupt sharing issue
2020-09-27 Add dev board image
2020-09-27 Millenial emoji thing...
2020-09-27 Millenial emoji thing, take 2
2020-09-27 kicad-exports v1 seems to be passé, moving on to 2.0...
2020-09-28 Add back the stm32 2U form factor /cc @joshajohnson
    [stm32_dev.kicad_pcb, stm32_dev.sch]
2020-09-28 Arguments for kicad-exports seem to have been changed in 2.0
2020-09-29 Remap USB pins on the STM32F042 the easy way...
2020-10-19 Add proper right/left button clicking/release thanks to Josh
2023-10-29 Fast forward to KiCad 7 ;)
    [stm32_dev.kicad_pcb]
